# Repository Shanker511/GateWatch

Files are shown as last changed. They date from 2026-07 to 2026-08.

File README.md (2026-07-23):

# GateWatch

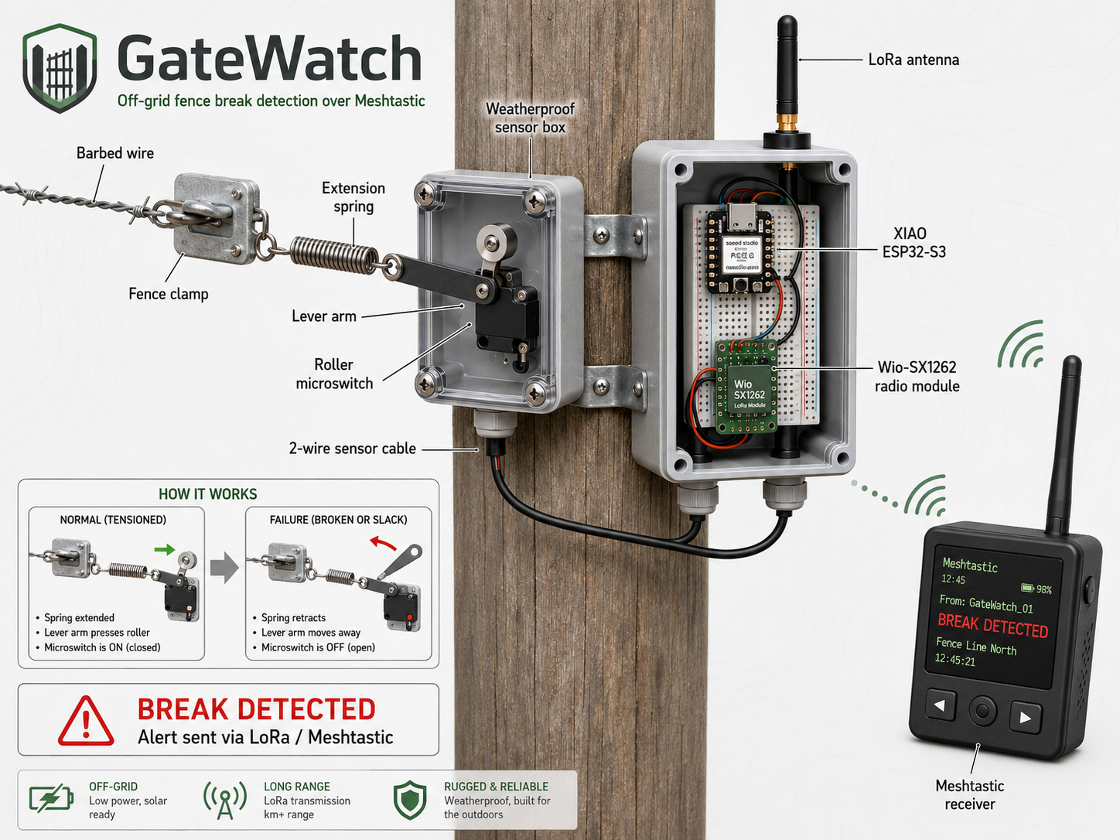
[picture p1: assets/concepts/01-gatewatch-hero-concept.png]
GateWatch concept


> **Current status:** hardware and firmware prototype in progress. The images in `assets/concepts/` are concept renderings, not photographs of a completed field unit. Real build photos, serial logs, range results, and a demonstration video will be added as testing progresses.

GateWatch is an off-grid fence integrity and activity monitor for farms, ranches, and remote property. A mechanical tension switch watches a barbed-wire fence section without electrically connecting the radio electronics to the fence. A PIR sensor provides a second indication of nearby movement. Alerts are transmitted through Meshtastic using a Seeed Studio XIAO ESP32-S3 and Wio-SX1262 radio module.

## Why this exists

A broken or slack fence may allow livestock to escape or create a security problem. Many fence lines are outside dependable cellular and Wi-Fi coverage. GateWatch is intended to provide a small, low-power field node that reports:

- `FENCE BREAK`
- `FENCE RESTORED`
- `MOTION DETECTED`
- `MOTION NEAR BROKEN FENCE`
- periodic status heartbeats
- a direct reply to `GW STATUS`

No cloud service or AI model is required for the core function.

## Project goals

| Goal | Status |
|---|---|
| Mechanical fence-tension sensor design | Designed; physical prototype pending |
| PIR motion input with cooldown | Implemented in prototype logic |
| XIAO ESP32-S3 + bare Wio-SX1262 wiring | Documented; bench validation pending |
| Standalone RadioLib smoke test | Source included; hardware build pending |
| Meshtastic firmware overlay | Source included; CI build validation pending |
| Desktop state-machine tests | Passing |
| Outdoor range and reliability test | Not started |
| Real prototype photos and demo video | Not started |

## Hardware

- Seeed Studio XIAO ESP32-S3
- Seeed Studio Wio-SX1262 bare radio module
- matched 868/915 MHz antenna for the configured region
- normally-closed roller-lever microswitch
- extension spring, lever, fence clamp, and weatherproof sensor box
- 3.3 V-compatible PIR motion sensor
- stable 3.3 V supply with local bulk and ceramic decoupling
- breadboard or perfboard for bench testing
- purpose-built carrier PCB for field use

The bare Wio-SX1262 is a surface-mount module. It cannot plug directly into a breadboard without a breakout, carrier PCB, or carefully strain-relieved wiring.

## System flow

```text
Barbed-wire tension mechanism ──> NC microswitch ──┐
                                                   ├─> XIAO ESP32-S3
PIR motion sensor ─────────────────────────────────┘         │
                                                             │ SPI
                                                             v
                                                       Wio-SX1262
                                                             │
                                                     Meshtastic mesh
                                                             │
                                                             v
                                                  Farmer's receiver/phone
```

## Correct prototype pin map

| Function | XIAO label | ESP32-S3 GPIO |
|---|---|---:|
| Wio DIO1 | D1 | 2 |
| Wio NRST | D2 | 3 |
| Wio BUSY | D3 | 4 |
| Wio NSS / CS | D4 | 5 |
| Wio RF switch / RXEN | D5 | 6 |
| Wio SCK | D8 | 7 |
| Wio MISO | D9 | 8 |
| Wio MOSI | D10 | 9 |
| Fence NC switch | D6 | 43 |
| PIR output | D7 | 44 |

See [`docs/WIRING.md`](docs/WIRING.md) before connecting hardware. The concept graphics are not authoritative wiring diagrams.

## Repository map

```text
assets/concepts/                 Ten concept renderings
firmware/radio_sensor_smoke_test Standalone RadioLib bench firmware
firmware/meshtastic-overlay      Custom Meshtastic variant and GateWatch module
docs/                            Build, wiring, safety, sensors, and test records
hardware/                        BOM and accurate wiring reference
simulator/                       Desktop state-machine model and tests
scripts/                         GitHub push and verification helpers
```

## Start testing

Read [`START_HERE.md`](START_HERE.md), then follow this order:

1. Review [`docs/SAFETY.md`](docs/SAFETY.md).
2. Build the breakout or carrier for the bare Wio-SX1262.
3. Wire the radio using [`docs/WIRING.md`](docs/WIRING.md).
4. Attach the correct antenna before transmitting.
5. Flash the standalone smoke test.
6. Verify fence and PIR state changes in the serial monitor.
7. Run the Meshtastic build workflow.
8. Record real test evidence in [`docs/FIELD_TEST_LOG_TEMPLATE.md`](docs/FIELD_TEST_LOG_TEMPLATE.md).

Desktop logic tests:

```bash
python -m unittest discover -s simulator -v
```

## Firmware tracks

### Standalone RadioLib smoke test

`firmware/radio_sensor_smoke_test/` tests the radio wiring and both sensors with ordinary point-to-point LoRa packets. It is deliberately separate from Meshtastic so hardware faults can be isolated first.

### Meshtastic overlay

`firmware/meshtastic-overlay/` adds:

- a custom `gatewatch-xiao-s3` hardware environment
- corrected exposed-header wiring for the bare Wio-SX1262
- fence and PIR input handling
- alert prioritization and message spacing
- heartbeat/status reporting
- `GW STATUS` and `GW HELP` commands

The overlay targets the current upstream Meshtastic source tree and is built by GitHub Actions. Until the workflow passes and real hardware is tested, treat this as development firmware rather than a finished release.

## License

GateWatch project code is released under GPL-3.0-or-later. Meshtastic and third-party libraries remain subject to their own upstream licenses.

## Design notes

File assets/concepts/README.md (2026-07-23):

# GateWatch Concept Renderings

These ten images describe the intended GateWatch product, deployment, and demonstration flow. They are concept artwork, not photographs and not authoritative wiring references.

1. Hero concept
2. System architecture concept
3. Mechanical tension sensor concept
4. Prototype wiring concept
5. Field deployment concept
6. Fence and motion event correlation
7. Enclosure exploded concept
8. Multi-zone coverage concept
9. Demonstration sequence concept
10. Farmer-use concept

Use `docs/WIRING.md` for actual pin assignments. Add real prototype photos under `assets/photos/`.

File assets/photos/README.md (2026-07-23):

# Real Prototype Photos

Add real, unedited build evidence here. Suggested filenames:

- `prototype-front.jpg`
- `prototype-wiring.jpg`
- `wio-carrier-closeup.jpg`
- `fence-sensor-installed.jpg`
- `field-test-wide.jpg`

Do not place concept renderings in this directory.

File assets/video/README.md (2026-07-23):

# Demo Video

Place a text file containing the final public video link here, or attach a compressed preview clip if repository size permits.

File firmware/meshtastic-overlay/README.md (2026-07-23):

# Meshtastic Overlay

This overlay adds a custom `gatewatch-xiao-s3` environment and a `GateWatchModule` to the official Meshtastic firmware source tree.

## Radio mapping

- D1 / GPIO2: Wio DIO1
- D2 / GPIO3: Wio NRST
- D3 / GPIO4: Wio BUSY
- D4 / GPIO5: Wio NSS/CS
- D5 / GPIO6: Wio RF_SW/RXEN
- D8 / GPIO7: Wio SCK
- D9 / GPIO8: Wio MISO
- D10 / GPIO9: Wio MOSI

## Sensor mapping

- D6 / GPIO43: normally-closed fence switch to ground
- D7 / GPIO44: active-high PIR output

## Build status

The source is intended to be compiled against current upstream Meshtastic firmware. The GitHub Actions workflow is the build authority. A successful desktop simulator test does not prove that this overlay compiles or that the radio wiring works.

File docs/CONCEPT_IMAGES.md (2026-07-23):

# Concept Image Notes

The ten images in `assets/concepts/` illustrate the intended product, field use, and presentation story. They were created before the physical prototype was assembled.

They are useful for:

- explaining the fence-tension mechanism
- showing the intended enclosure and deployment
- describing multi-zone mesh coverage
- planning the demonstration video
- communicating the motion/fence event logic

They are not authoritative for:

- exact pin assignments
- electrical voltage levels
- component dimensions
- final enclosure construction
- proof that the hardware has been built

Use `docs/WIRING.md` and `hardware/wiring-reference.svg` for wiring. Replace or supplement concept images with real photographs before competition judging.

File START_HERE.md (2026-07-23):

# GateWatch — Start Here

This repository targets a **Seeed Studio XIAO ESP32-S3**, a **bare Wio-SX1262 module**, a normally-closed mechanical fence-tension switch, and a 3.3 V-compatible PIR sensor.

## Do this first

1. Read `docs/SAFETY.md`.
2. Read `docs/WIRING.md` and verify every Wio module pad before soldering.
3. Build or obtain a carrier/breakout for the bare module. Do not hang jumper wires directly from unsupported pads.
4. Attach the correct antenna before powering firmware that may transmit.
5. Power the radio from 3.3 V only.

## Validation sequence

### 1. Run desktop tests

```powershell
python -m unittest discover -s simulator -v
```

### 2. Flash the standalone smoke test

```powershell
cd firmware\radio_sensor_smoke_test
python -m pip install platformio
python -m platformio run -e gatewatch-smoke-tx
python -m platformio run -e gatewatch-smoke-tx --target upload
python -m platformio device monitor --baud 115200
```

Expected serial events:

```text
BOOT fence=SECURE
FENCE BREAK
FENCE RESTORED
MOTION DETECTED
MOTION NEAR BROKEN FENCE
HEARTBEAT fence=SECURE motion=IDLE
```

### 3. Build the Meshtastic overlay

Windows PowerShell:

```powershell
cd firmware\meshtastic-overlay
.\scripts\build.ps1
```

Linux/macOS:

```bash
cd firmware/meshtastic-overlay
./scripts/build.sh
```

The GitHub Actions workflow performs the same build after the repository is pushed.

### 4. Collect evidence

Use `docs/FIELD_TEST_LOG_TEMPLATE.md` and add real photographs under `assets/photos/`. Concept art is not accepted as authenticity evidence.

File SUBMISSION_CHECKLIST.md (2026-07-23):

# Meshtastic Build-Off Submission Checklist

## Repository

- [x] Public project repository structure
- [x] Detailed README
- [x] Open-source license
- [x] Firmware source
- [x] Installation and build instructions
- [x] Hardware BOM
- [x] Wiring documentation
- [x] Safety notes
- [x] Test plan
- [ ] GitHub Actions Meshtastic build passes
- [ ] Release binary attached

## Authenticity and evidence

- [ ] Real front-view prototype photo
- [ ] Real wiring/carrier photo
- [ ] Real installed fence-sensor photo
- [ ] Meshtastic alert screenshot
- [ ] Serial initialization log
- [ ] Range-test log
- [ ] Power-test result
- [ ] Demo video of at least 30 seconds

## Technical validation

- [ ] SX1262 initializes without error
- [ ] Fence break alert repeats reliably
- [ ] Fence restoration alert repeats reliably
- [ ] PIR warm-up confirmed
- [ ] PIR cooldown confirmed
- [ ] Combined event alert confirmed
- [ ] Private Meshtastic channel configured
- [ ] Legal LoRa region configured
- [ ] Outdoor wiring strain relieved

## Presentation

- [ ] Problem and target user clearly explained
- [ ] Meshtastic is essential to the solution
- [ ] Known limitations listed
- [ ] Concept images labeled as concepts
- [ ] Real failures and fixes documented
- [ ] Final repository commit/tag created

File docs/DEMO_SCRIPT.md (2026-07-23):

# 60–90 Second Demo Script

1. Show the real XIAO ESP32-S3, Wio-SX1262, antenna, tension switch, and PIR sensor.
2. Show the receiver node and Meshtastic app.
3. State: “GateWatch monitors fence tension and nearby motion without cellular service.”
4. Show the fence wire under tension and confirm `SECURE`.
5. Release or cut the test wire.
6. Show the mechanical lever releasing the normally-closed microswitch.
7. Show the `FENCE BREAK` alert arriving on the receiver.
8. Trigger the PIR while the fence remains broken.
9. Show `MOTION NEAR BROKEN FENCE`.
10. Restore tension and show `FENCE RESTORED`.
11. End with a wide shot of both nodes and the actual test distance.

Do not use concept images as a substitute for the real demonstration.

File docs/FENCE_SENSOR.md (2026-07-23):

# Mechanical Fence Sensor

## Principle

Barbed wire is a poor supervised electrical conductor because it contacts ground, vegetation, staples, posts, moisture, corrosion, and other fence strands. GateWatch instead detects the mechanical result of a break: loss of tension.

## Mechanism

```text
barbed wire -> approved fence clamp -> extension spring -> lever -> NC roller microswitch
```

Normal tension holds the microswitch closed. A break, released clamp, or severe slack allows the spring and lever to move, opening the switch.

## Adjustment

- Mount the mechanism at a brace or termination post.
- Use an adjustment bolt or slotted bracket to set the trigger point.
- Keep the microswitch and electrical terminations inside a weather-resistant box.
- Do not make the small switch carry the fence's full structural load. A separate mechanical stop must absorb excessive tension.
- Divide long fences into named sections; one switch reports the affected section, not the exact break location.

Suggested node names include `GW-NORTH-01`, `GW-WEST-02`, and `GW-EAST-GATE`.

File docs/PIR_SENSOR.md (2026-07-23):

# PIR Motion Sensor

The PIR input is supplemental evidence. It does not identify a person or distinguish a human from livestock, wildlife, moving vegetation, or rapid temperature changes.

## Firmware controls

- 30-second start-up warm-up
- 200 ms input debounce
- 60-second event cooldown
- Separate motion state from fence state
- Combined high-priority alert when motion occurs while the fence state is broken

## Placement

Mount the PIR below or beside the radio enclosure and point it along the approach corridor rather than directly at the sky, sun, reflective water, or rapidly heating metal. A hood reduces rain and direct solar exposure.

For first tests, use a small 3.3 V PIR module. Confirm its output voltage with a meter before connecting it to the XIAO.

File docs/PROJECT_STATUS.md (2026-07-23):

# Project Status

## Completed in repository

- problem definition and architecture
- mechanical fence-tension sensor design
- PIR event behavior
- standalone RadioLib smoke-test source
- Meshtastic overlay source
- desktop sensor-state simulator
- automated desktop tests
- BOM, wiring, safety, test plan, and concept materials

## Not yet validated

- soldered Wio-SX1262 carrier
- radio initialization on the user's exact module revision
- Meshtastic overlay compilation in GitHub Actions
- end-to-end Meshtastic message reception
- mechanical trigger repeatability
- outdoor weather resistance
- battery life and solar charging
- range testing

## Evidence policy

Generated concept images are retained as design and presentation material. They must not be represented as photographs of the physical build. Add real evidence to:

```text
assets/photos/
assets/screenshots/
assets/video/
docs/test-results/
```

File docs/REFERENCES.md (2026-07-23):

# References

- Meshtastic firmware repository: https://github.com/meshtastic/firmware
- Meshtastic Detection Sensor module documentation: https://meshtastic.org/docs/configuration/module/detection-sensor/
- Meshtastic issue documenting the exposed-header Wio-SX1262 pin definition: https://github.com/meshtastic/firmware/issues/8409
- Seeed Studio Meshtastic Build-Off 2026: https://www.seeedstudio.com/meshtastic-build-off
- Official competition repository: https://github.com/Seeed-Projects/meshtastic-build-off-2026
- Seeed Studio XIAO ESP32-S3 pin multiplexing: https://wiki.seeedstudio.com/xiao_esp32s3_pin_multiplexing/
- Wio-SX1262 product page: https://www.seeedstudio.com/Wio-SX1262-Wireless-Module-p-5981.html

Pin assignments and software interfaces can change. Freeze a known Meshtastic commit after the first successful build and hardware test.

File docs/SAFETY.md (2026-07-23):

# Safety

- Do not connect the XIAO, Wio-SX1262, microswitch, PIR, or breadboard directly to an energized electric-fence conductor.
- GateWatch v0.2 uses a mechanically actuated, electrically isolated switch.
- Barbed wire can cut skin and can release stored energy when tension changes. Wear eye protection, gloves, long sleeves, and use proper fence tools.
- Install a mechanical stop so the microswitch and enclosure do not carry fence tension.
- Never transmit without the correct antenna attached.
- Do not place a breadboard prototype outdoors unattended.
- Use a protected battery, fused wiring, strain relief, weather-rated cable glands, and a sealed enclosure for field trials.
- Follow local radio-region settings and applicable fencing, electrical, workplace, and land-use requirements.

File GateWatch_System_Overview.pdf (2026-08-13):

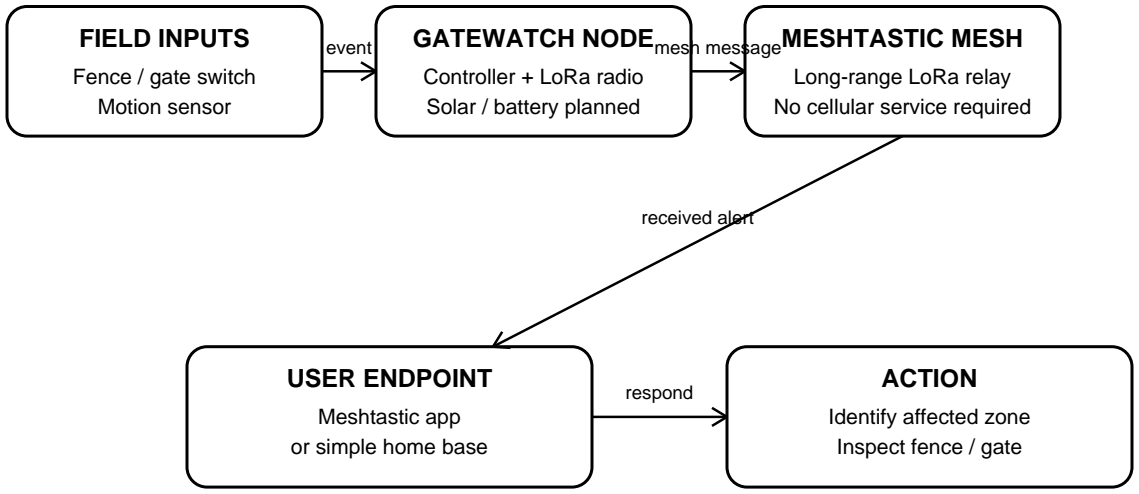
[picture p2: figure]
FIELD INPUTS; Fence / gate switch Motion sensor; GATEWATCH NODE; Controller + LoRa radio Solar / battery planned; MESHTASTIC MESH; Long-range LoRa relay No cellular service required; event; mesh message; USER ENDPOINT; Meshtastic app or simple home base; ACTION; Identify affected zone Inspect fence / gate; received alert; respond

GateWatch - Meshtastic Build-Off 2026 | Page 1

# GateWatch

How the Meshtastic Fence Monitoring System Works

Project: GateWatch / Farmer's Fence Mesh | Build-Off: Meshtastic Build-Off 2026
Purpose: Remote fence, gate, and movement alerts | Status: Concept / design; physical validation pending

## 1. What GateWatch Is

GateWatch is a proposed low-power monitoring system for farms and ranches where long fence lines may be outside cellular or Wi-Fi coverage. A small field node watches for conditions such as a fence breach, an open gate, or nearby movement. When an event is detected, the node sends a message through a Meshtastic LoRa mesh to the farmer's phone or a simple home-base device.

The design is intended to reduce the time spent manually checking remote fence sections and to provide an early warning when livestock containment or property security may be affected.

## 2. System Architecture

The key idea is simple: sensors generate an event, a field node converts that event into a message, Meshtastic carries the message across the property, and the user receives enough information to decide where to inspect.

## 3. How an Alert Moves Through the System

### 1. Monitor

A GateWatch field node continuously watches connected inputs. Planned examples include a fence or gate switch and a motion sensor.

### 2. Detect

If an input changes state - for example, a gate opens or a fence-monitoring switch indicates a possible breach - the controller records the event.

### 3. Package

The controller creates a short alert message identifying the node or monitored zone and the type of event.

### 4. Transmit

The LoRa radio sends the alert into the Meshtastic network. Nearby Meshtastic nodes can relay the packet, allowing coverage beyond a single direct radio link.

### 5. Receive

The alert reaches a Meshtastic-connected phone or a simple wireless home-base device.

### 6. Respond

The user can identify the affected section and inspect the fence, gate, post, or surrounding area.

## 4. Main System Blocks

Block | Role in GateWatch
Field sensors | Detect physical changes such as gate state, fence condition, or motion.
Controller | Reads sensors, applies event logic, and creates an alert.
LoRa radio | Provides long-range, low-bandwidth wireless communication.
Meshtastic mesh | Relays messages between nodes without requiring normal cellular infrastructure.
Power system | Planned solar and battery power for remote, low-maintenance operation.
User endpoint | Meshtastic app or simple base station used to receive alerts and identify the affected area.

## 5. Example Deployment

A ranch could place GateWatch nodes at high-risk locations such as gates, isolated fence corners, road crossings, or sections frequently damaged by wildlife or fallen branches. The nodes would communicate through the Meshtastic mesh, so a node that cannot directly reach the house could potentially pass its alert through another mesh node.

### Example event:

Fence section B changes state -> GateWatch Node B detects the event -> the node transmits an alert -> the message is relayed through the Meshtastic mesh -> the farmer receives the alert and checks section B.

## 6. Why Meshtastic Fits the Concept

GateWatch is aimed at locations where conventional infrastructure may be unavailable or undesirable. Meshtastic uses LoRa radios and mesh networking, making it suitable for small event messages over comparatively long distances while allowing intermediate nodes to relay traffic.

The project is not intended to stream video or large amounts of data. Its job is to move small, useful status and alarm messages from remote points back to the user.

## 7. Current Project Status

As of the Meshtastic Build-Off 2026 final review period, GateWatch should be treated as a concept and system design rather than a completed, field-validated product. The physical prototype, measured radio range, solar/battery endurance, environmental enclosure performance, and real-world sensor behavior still require testing.

This document describes the intended operation of the system. It does not claim that the full system has already been assembled or validated in the field.

## 8. Next Build Milestones

- Assemble one field node and verify its sensor inputs.
- Establish Meshtastic radio communication between the field node and a receiving node.
- Generate real fence/gate and movement events and confirm alert delivery.
- Measure practical range on representative rural terrain.
- Measure current draw and validate the solar/battery power budget.
- Install the electronics in a weather-resistant enclosure and perform an outdoor field trial.

### Repository

https://github.com/Shanker511/GateWatch

Prepared as a concise technical overview for the GateWatch Meshtastic Build-Off project.

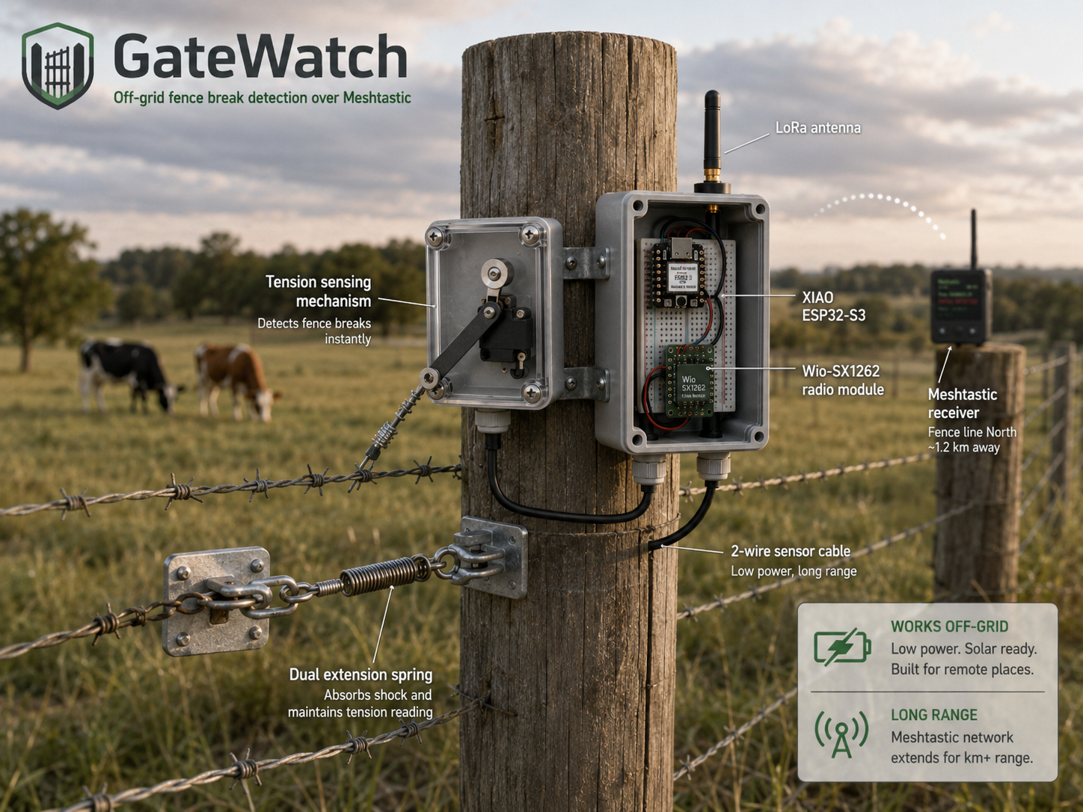
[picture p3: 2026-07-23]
assets/concepts/05-field-deployment-concept.png

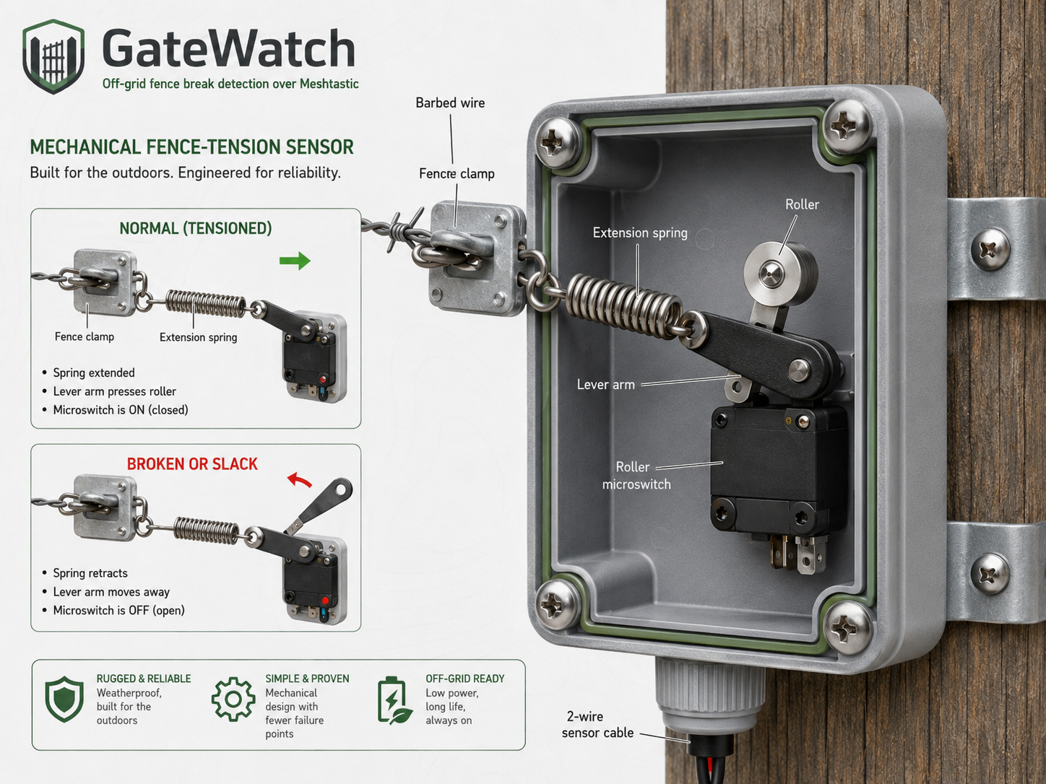
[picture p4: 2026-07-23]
assets/concepts/03-mechanical-tension-sensor-concept.png

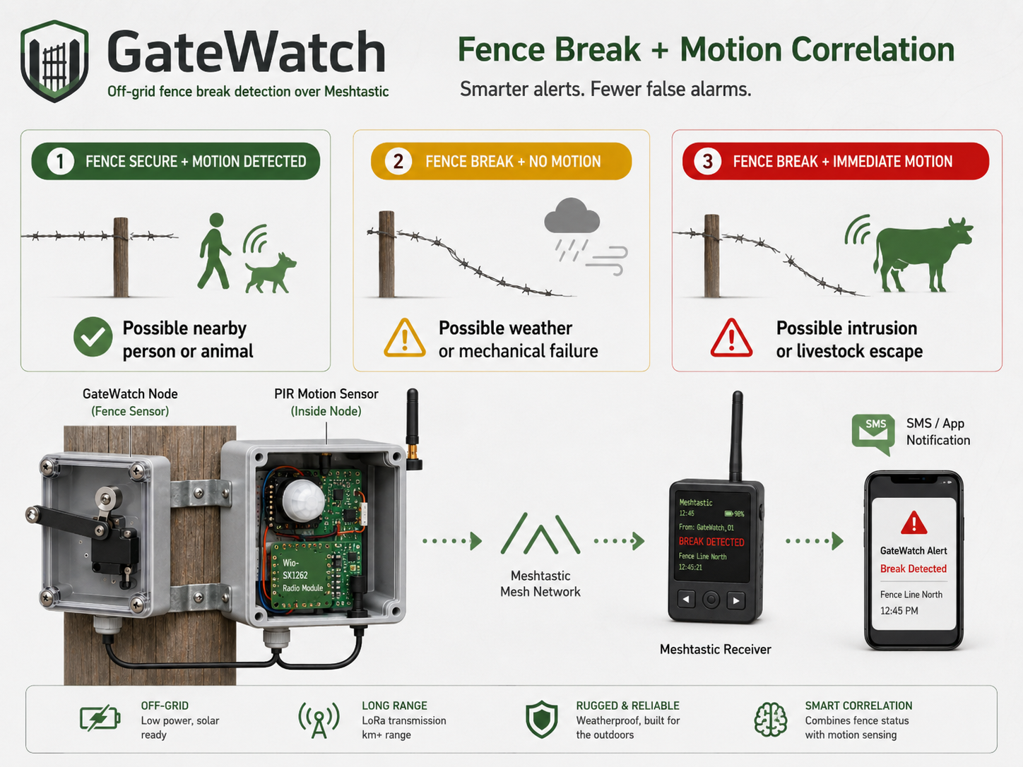
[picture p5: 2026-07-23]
assets/concepts/06-motion-correlation-concept.png

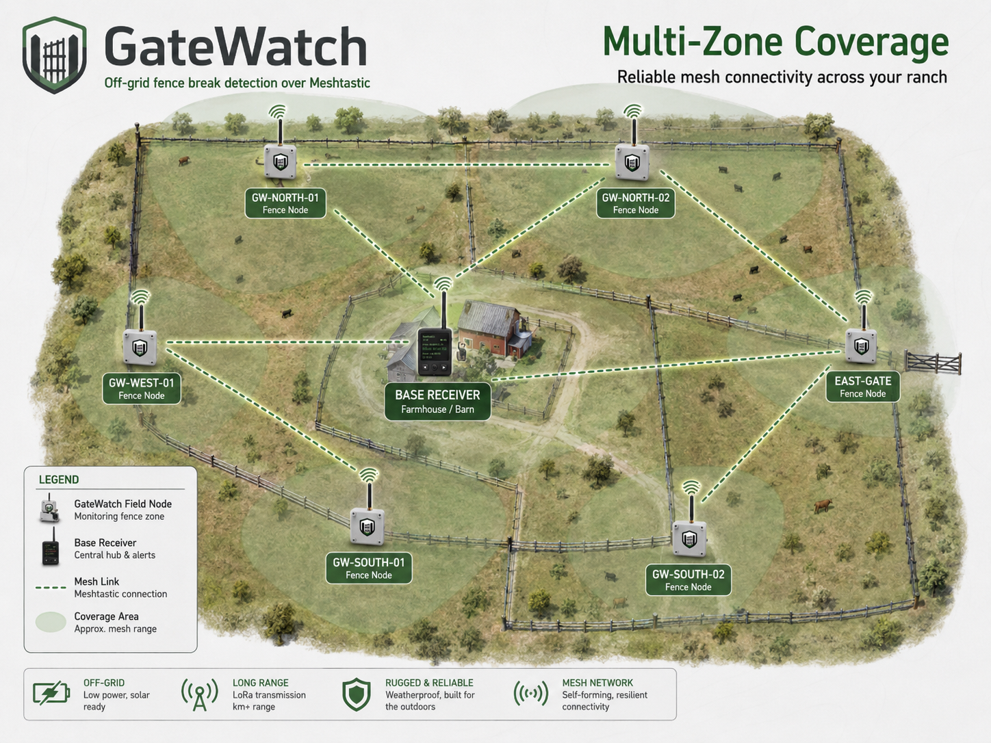
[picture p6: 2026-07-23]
assets/concepts/08-multi-zone-coverage-concept.png

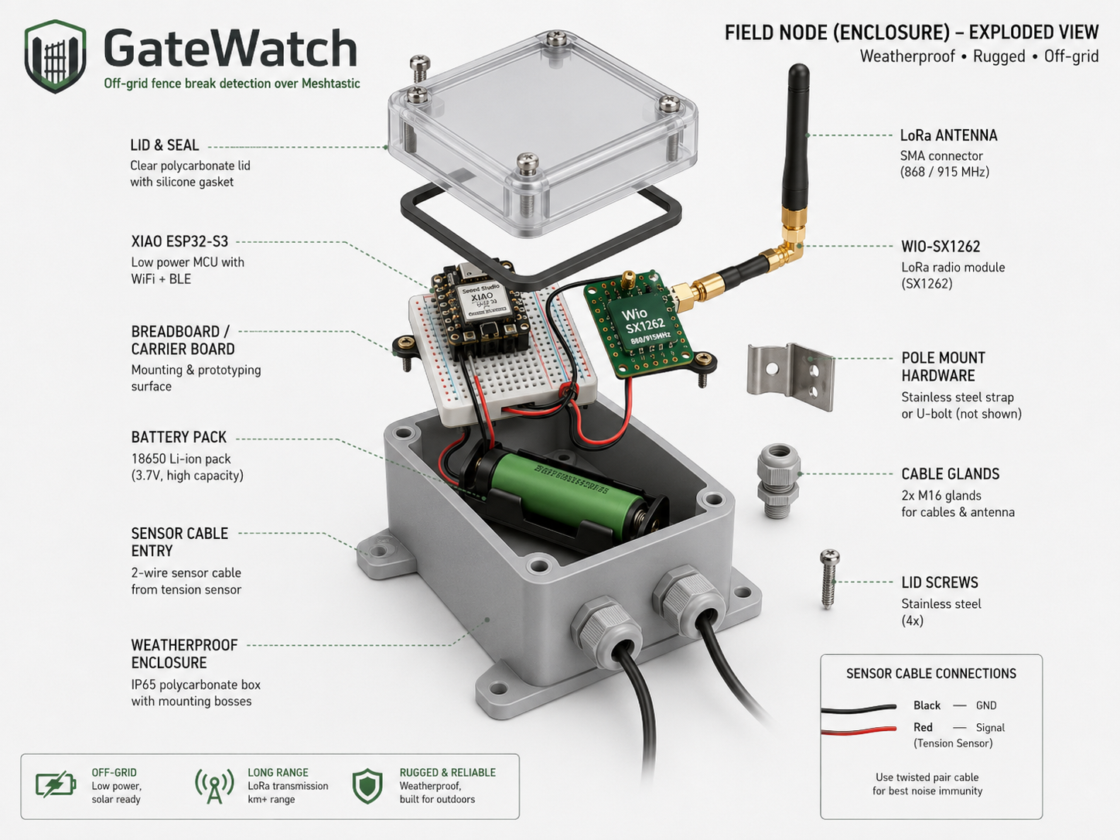
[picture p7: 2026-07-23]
assets/concepts/07-enclosure-exploded-concept.png

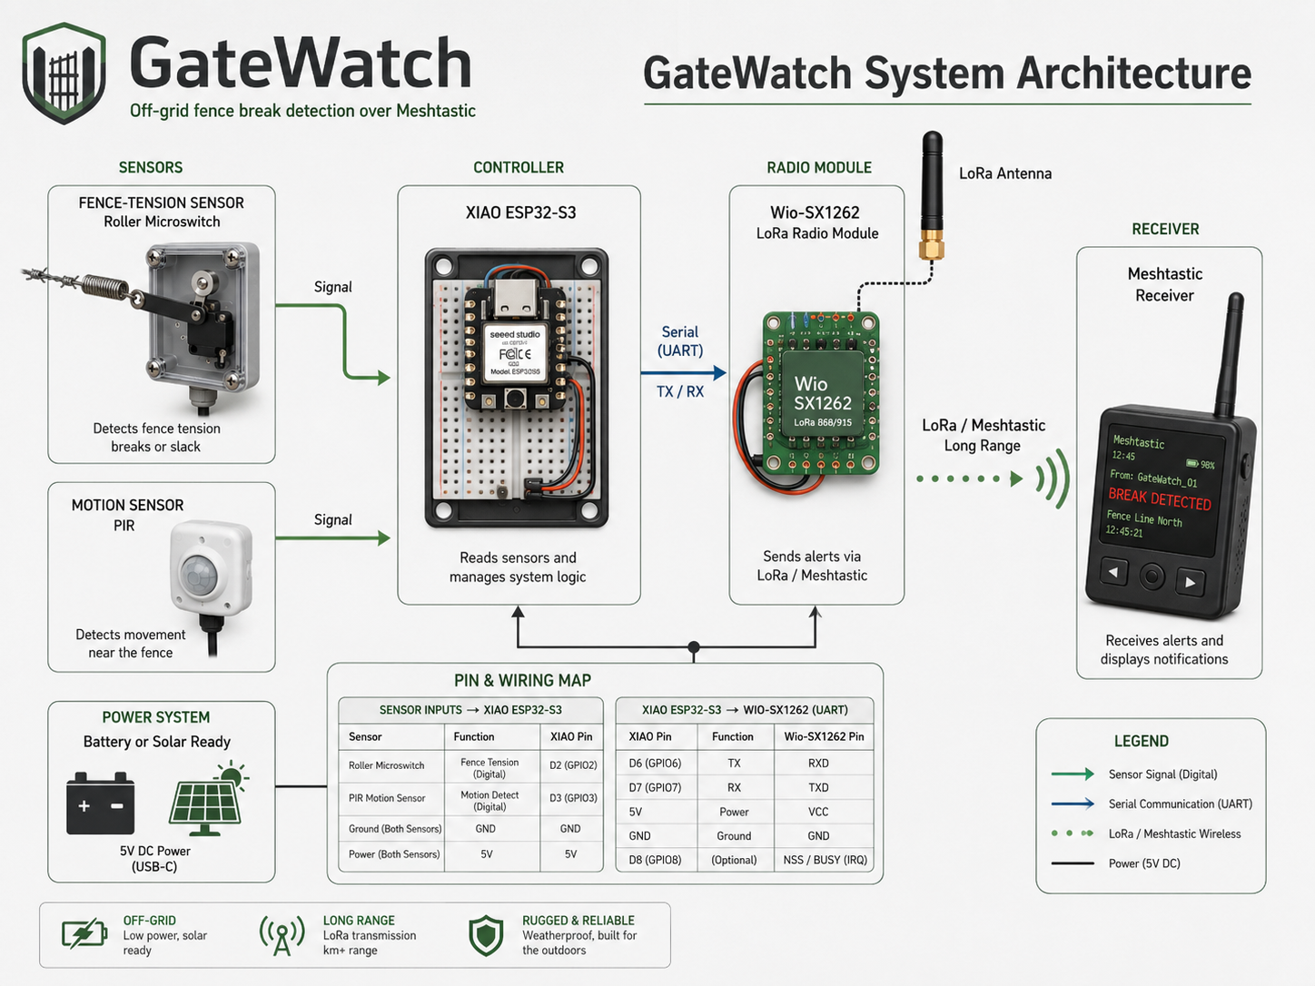
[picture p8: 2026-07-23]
assets/concepts/02-system-architecture-concept.png

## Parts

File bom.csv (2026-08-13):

Item | Quantity | Node | Stage | Notes
Seeed Studio XIAO ESP32-S3 | 3 | Base + 2 Sentinels | Required | Host MCU
Seeed Studio Wio-SX1262 bare module | 3 | Base + 2 Sentinels | Required | SX1262 Meshtastic radio
Matched 868/915 MHz antenna | 3 | Base + 2 Sentinels | Required | Match configured legal region and attach before transmit
Wio-SX1262 breakout/carrier PCB | 3 | Base + 2 Sentinels | Required | Bare module cannot plug directly into a breadboard
Normally-closed roller-lever microswitch | 2 | Sentinels | Required | Fence-tension input
3.3 V-compatible PIR motion sensor | 2 | Sentinels | Required | Active-high output preferred
DHT11 temperature/humidity module | 2 | Sentinels | Required | Use a vented shaded chamber
4.7-5.1 kOhm resistor | 2 | Sentinels | Conditional | Required for bare four-pin DHT11; many modules include it
Extension spring | 2 | Sentinels | Required | Mechanical tension mechanism
Fence wire clamp | 2 | Sentinels | Required | Use fencing-rated hardware
Lever arm and pivot hardware | 2 | Sentinels | Required | Adjustable trigger geometry
Weather-resistant sensor enclosure | 2 | Sentinels | Field test | Protect switch mechanism
Weather-resistant electronics enclosure | 2 | Sentinels | Field test | Protect radio electronics
Vented DHT11 radiation shield or chamber | 2 | Sentinels | Field test | Protect from rain and direct sun while allowing airflow
Cable glands | 6-8 | Sentinels | Field test | Strain relief and weather sealing
100 uF electrolytic capacitor | 3 | Base + 2 Sentinels | Required | Place near each radio supply
100 nF ceramic capacitor | 6 | Base + 2 Sentinels | Required | Radio decoupling plus DHT11 supply filtering
1 kOhm resistor | 2 | Sentinels | Recommended | Fence input protection
Two-conductor UV-resistant cable | As needed | Sentinels | Field test | Sensor to electronics enclosure
Breadboard and jumper wires | 3 | Bench only | Bench only | Not suitable for outdoor deployment
USB power supply | 1 | Base | Required | Continuous dashboard bridge power
Protected battery pack or USB power | 2 | Sentinels | Bench/field | Confirm voltage regulation and current capability

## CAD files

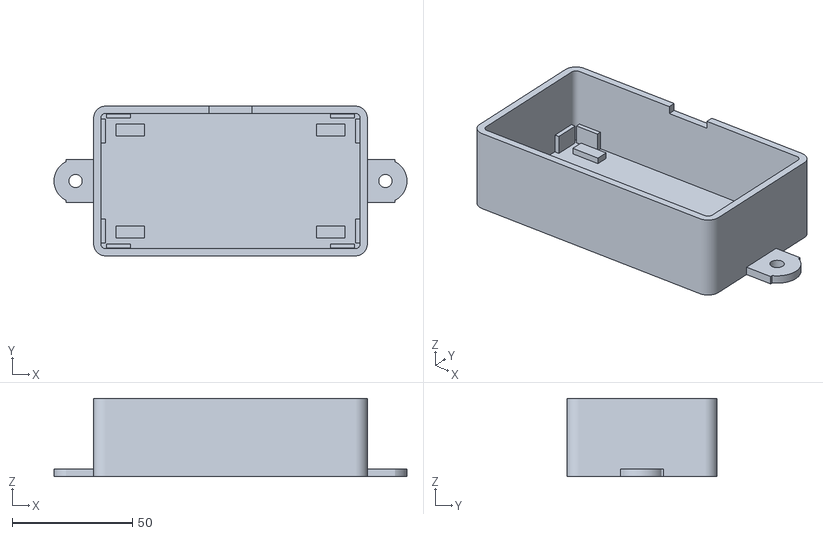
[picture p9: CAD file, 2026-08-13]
GateWatch_Base.stl
147.0 x 62.4 x 32.6

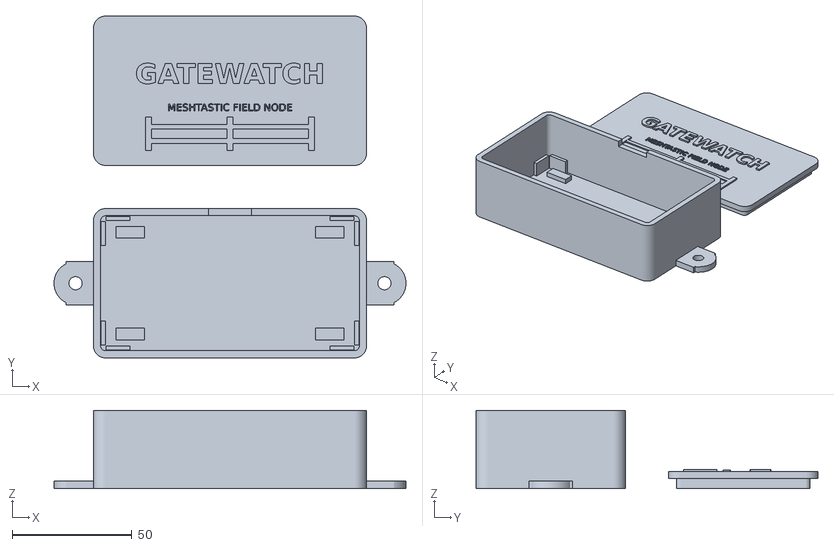
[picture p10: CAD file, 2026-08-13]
GateWatch_PrintPlate.stl
147.0 x 142.8 x 32.6

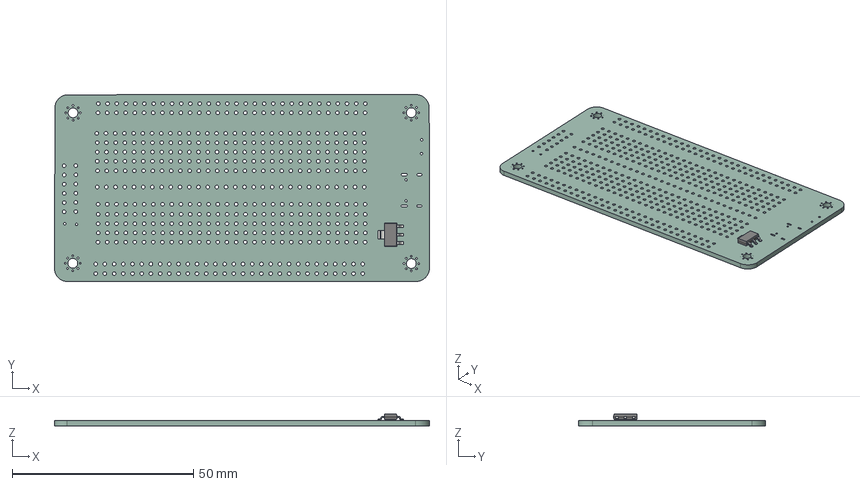
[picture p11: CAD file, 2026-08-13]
.step
103.4 x 51.6 x 3.34 mm
SOT-223
Protoboard_PCB

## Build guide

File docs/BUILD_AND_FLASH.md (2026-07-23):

# Build and Flash

## Standalone smoke test

The smoke test verifies the XIAO, Wio-SX1262 wiring, tension switch, PIR sensor, and point-to-point LoRa transmission before the full Meshtastic build is introduced.

Requirements:

- Python 3
- PlatformIO Core or VS Code with PlatformIO
- USB data cable
- antenna attached to the Wio-SX1262

```bash
cd firmware/radio_sensor_smoke_test
python -m pip install platformio
python -m platformio run -e gatewatch-smoke-tx
python -m platformio run -e gatewatch-smoke-tx --target upload
python -m platformio device monitor --baud 115200
```

Optional matching point-to-point receiver:

```bash
python -m platformio run -e gatewatch-smoke-rx
python -m platformio run -e gatewatch-smoke-rx --target upload
```

The smoke-test packets are ordinary LoRa packets and are not Meshtastic-compatible.

## Meshtastic overlay

Windows:

```powershell
cd firmware\meshtastic-overlay
.\scripts\build.ps1
```

Linux/macOS:

```bash
cd firmware/meshtastic-overlay
./scripts/build.sh
```

The scripts clone the official firmware, apply the GateWatch variant and module, patch module initialization, and run PlatformIO.

Set `MESHTASTIC_REF` to a known release or commit when freezing a tested competition build.

After flashing:

1. Set the legal LoRa region.
2. Configure a private primary channel shared by the field node and receiver.
3. Confirm normal text messages between the nodes.
4. Trigger the fence switch and PIR.
5. Send `GW STATUS` from the receiver.

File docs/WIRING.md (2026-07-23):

# Wiring Reference

This document is the authoritative prototype wiring reference. The images under `assets/concepts/` are communication artwork and may simplify or mislabel details.

## Bare Wio-SX1262 to XIAO ESP32-S3

The following exposed-header mapping is based on the working header-board pin definition documented in the Meshtastic firmware project.

| Wio signal | XIAO label | ESP32-S3 GPIO | Notes |
|---|---|---:|---|
| DIO1 | D1 | 2 | SX1262 interrupt |
| NRST | D2 | 3 | Radio reset |
| BUSY | D3 | 4 | Radio busy line |
| NSS / CS | D4 | 5 | SPI chip select |
| RF_SW / RXEN | D5 | 6 | External receive switch control |
| SCK | D8 | 7 | SPI clock |
| MISO | D9 | 8 | SPI radio to MCU |
| MOSI | D10 | 9 | SPI MCU to radio |
| VCC | 3V3 | — | 3.3 V only |
| GND | GND | — | Connect all grounds |
| ANT | U.FL/IPEX | — | Matched antenna; no GPIO connection |

Use short wiring and a solid ground reference. Add a 100 µF electrolytic capacitor and a 100 nF ceramic capacitor close to the radio module.

## Fence tension switch

Use the normally-closed contact. This creates a fail-safe behavior where a broken sensor cable also appears as an alarm.

```text
XIAO D6 / GPIO43 ---- microswitch NC
GND ----------------- microswitch COM
```

Firmware mode: `INPUT_PULLUP`

| Electrical state | Reading | GateWatch state |
|---|---|---|
| NC switch closed | LOW | SECURE |
| Switch open | HIGH | FENCE BREAK |
| Cable cut/disconnected | HIGH | FENCE BREAK |

For long cable runs, place a 1 kΩ series resistor near the XIAO input and a 100 nF capacitor from the GPIO side of the resistor to ground.

## PIR motion sensor

Only use a PIR output that is safe for 3.3 V logic.

```text
PIR VCC ---- XIAO 3V3
PIR GND ---- XIAO GND
PIR OUT ---- XIAO D7 / GPIO44
```

| PIR output | GateWatch state |
|---|---|
| LOW | IDLE |
| HIGH | MOTION |

The firmware ignores PIR activity during warm-up and applies a cooldown to prevent mesh flooding.

## Breadboard warning

The Wio-SX1262 is a surface-mount module. It must be mounted to a breakout, carrier, or mechanically secured perfboard assembly. Do not use unsupported flying wires attached directly to the module pads for field testing.

## Power

- Wio-SX1262 supply: 3.3 V only
- Bench power: XIAO USB-C is acceptable
- Place decoupling close to the radio
- Attach the antenna before transmitting
- Set the legal Meshtastic region before over-the-air tests

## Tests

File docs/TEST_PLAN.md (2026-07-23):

# Test Plan

Record every test with date, firmware commit, node name, power source, antenna, distance, weather, result, and photo/video reference.

## Bench tests

1. Boot with fence switch closed. Verify `SECURE` and no false break event.
2. Open switch for less than debounce time. Verify no alert.
3. Hold switch open. Verify one `FENCE BREAK` alert.
4. Close switch. Verify one `FENCE RESTORED` alert.
5. Trigger PIR after warm-up. Verify one `MOTION DETECTED` alert.
6. Retrigger PIR during cooldown. Verify no message flood.
7. Open fence switch, then trigger PIR. Verify `MOTION NEAR BROKEN FENCE`.
8. Send `GW STATUS`. Verify direct status reply.
9. Leave operating for at least one heartbeat interval. Verify status heartbeat.
10. Power-cycle with fence open. Verify startup state is reported correctly after initialization.

## Field tests

- Test at 25 m, 100 m, 250 m, and a realistic property distance.
- Test normal line of sight and with terrain/building obstruction.
- Operate for at least four hours on the intended battery.
- Pull, release, and repair the mechanical test fence several times.
- Note false triggers from wind, livestock contact, thermal changes, and enclosure movement.

## Pass criteria

- Every sustained break produces exactly one break alert within the configured timing window.
- Every restoration produces exactly one restoration alert.
- PIR events remain rate-limited.
- Status command receives a reply.
- No resets or radio initialization failures occur during the field session.

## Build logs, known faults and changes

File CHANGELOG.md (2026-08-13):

# Changelog

## 0.5.2 — 2026-07-22

- Standardized the build as one Base node and two identical Sentinel nodes.
- Added DHT11 temperature and humidity sensing on XIAO D0 / GPIO1.
- Added DHT11 sampling to the standalone smoke test and Meshtastic overlay.
- Added `GW ENV` command and environmental fields in status and heartbeat messages.
- Added dashboard temperature/humidity parsing, storage, display, demo data, and tests.
- Updated the three-node BOM and authoritative wiring documentation.

## 0.5.1 — 2026-07-22

- Added a double-click Windows GitHub publishing helper.
- Updated the automated commit message for the dashboard gallery and dark-theme additions.
- Re-ran repository verification before packaging.

## 0.5.0 — 2026-07-22

- Added dashboard and mobile concept screenshots in both light and dark themes.
- Added screenshot gallery to the main README.
- Added documentation clarifying the dashboard visual direction and current dark operational theme.
- Updated dashboard docs so the repository presents a clearer product story for the Meshtastic Build-Off.

## 0.4.0 — 2026-07-22

- Added the local GateWatch map dashboard.
- Added GeoJSON import and export, node placement, and zone drawing.
- Added the Meshtastic USB bridge and live dashboard updates.
- Added dashboard server tests and example demo state.

## 0.2.0 — 2026-07-22

- Reworked field node for XIAO ESP32-S3 and bare Wio-SX1262 module.
- Added fence tension-loss input.
- Added PIR motion input with warm-up, debounce, and cooldown protection.
- Added combined `MOTION NEAR BROKEN FENCE` alert.
- Added `GW STATUS` and `GW HELP` Meshtastic commands.
- Added scheduled heartbeat and outbound message spacing.
- Added standalone LoRa hardware smoke test.
- Added desktop simulator and automated tests.

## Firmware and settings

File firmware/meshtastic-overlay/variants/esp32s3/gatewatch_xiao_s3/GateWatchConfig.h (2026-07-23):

#pragma once

// Human-readable identity included in every GateWatch application message.
#define GATEWATCH_NODE_NAME "GW-NORTH-01"

// Sensors on exposed XIAO header pins.
#define GATEWATCH_FENCE_PIN 43 // XIAO D6; NC switch to GND
#define GATEWATCH_PIR_PIN 44   // XIAO D7; active HIGH

#define GATEWATCH_FENCE_BREAK_LEVEL HIGH
#define GATEWATCH_PIR_ACTIVE_LEVEL HIGH

#define GATEWATCH_FENCE_DEBOUNCE_MS 750UL
#define GATEWATCH_PIR_DEBOUNCE_MS 200UL
#define GATEWATCH_PIR_WARMUP_MS 30000UL
#define GATEWATCH_PIR_COOLDOWN_MS 60000UL
#define GATEWATCH_HEARTBEAT_MS 900000UL
#define GATEWATCH_TX_SPACING_MS 15000UL
#define GATEWATCH_STARTUP_REPORT_MS 35000UL

// Meshtastic channel index used for broadcast alerts. Channel 0 is the primary channel.
#define GATEWATCH_ALERT_CHANNEL 0

// Bell character can trigger audible/vibration notifications in some clients.
#define GATEWATCH_APPEND_BELL 1

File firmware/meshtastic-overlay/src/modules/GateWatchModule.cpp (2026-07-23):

#include "GateWatchModule.h"

#include "GateWatchConfig.h"
#include "MeshService.h"
#include "mesh/Channels.h"
#include "configuration.h"
#include "main.h"

#include <Arduino.h>
#include <ctype.h>
#include <stdio.h>
#include <string.h>

GateWatchModule::GateWatchModule()
    : SinglePortModule("gatewatch", meshtastic_PortNum_TEXT_MESSAGE_APP), concurrency::OSThread("GateWatch")
{
}

bool GateWatchModule::updateInput(DebouncedInput &input, bool raw, uint32_t debounceMs, uint32_t now)
{
    if (!input.initialized) {
        input.raw = raw;
        input.stable = raw;
        input.changedAt = now;
        input.initialized = true;
        return false;
    }

    if (raw != input.raw) {
        input.raw = raw;
        input.changedAt = now;
    }

    if (input.stable != input.raw && (uint32_t)(now - input.changedAt) >= debounceMs) {
        input.stable = input.raw;
        return true;
    }
    return false;
}

int32_t GateWatchModule::runOnce()
{
    const uint32_t now = millis();

    if (firstRun) {
        firstRun = false;
        bootAt = now;
        lastHeartbeatAt = now;
        pinMode(GATEWATCH_FENCE_PIN, INPUT_PULLUP);
        pinMode(GATEWATCH_PIR_PIN, INPUT_PULLDOWN);

        const bool rawFenceBroken = digitalRead(GATEWATCH_FENCE_PIN) == GATEWATCH_FENCE_BREAK_LEVEL;
        const bool rawPirActive = digitalRead(GATEWATCH_PIR_PIN) == GATEWATCH_PIR_ACTIVE_LEVEL;
        updateInput(fenceInput, rawFenceBroken, 0, now);
        updateInput(pirInput, rawPirActive, 0, now);
        fenceBroken = fenceInput.stable;
        pirActive = false; // Ignore PIR state until warm-up completes.

        LOG_INFO("GateWatch initialized: fence=%s", fenceBroken ? "BROKEN" : "SECURE");
        return setStartDelay();
    }

    const bool rawFenceBroken = digitalRead(GATEWATCH_FENCE_PIN) == GATEWATCH_FENCE_BREAK_LEVEL;
    if (updateInput(fenceInput, rawFenceBroken, GATEWATCH_FENCE_DEBOUNCE_MS, now)) {
        onFenceChanged(fenceInput.stable, now);
    }

    const bool pirWarmed = (uint32_t)(now - bootAt) >= GATEWATCH_PIR_WARMUP_MS;
    if (pirWarmed) {
        const bool rawPirActive = digitalRead(GATEWATCH_PIR_PIN) == GATEWATCH_PIR_ACTIVE_LEVEL;
        if (updateInput(pirInput, rawPirActive, GATEWATCH_PIR_DEBOUNCE_MS, now)) {
            onPirChanged(pirInput.stable, now);
        }
    }

    if (!startupQueued && (uint32_t)(now - bootAt) >= GATEWATCH_STARTUP_REPORT_MS) {
        startupQueued = true;
        queueStatus(BROADCAST_NODE, GATEWATCH_ALERT_CHANNEL, false);
    }

    if ((uint32_t)(now - lastHeartbeatAt) >= GATEWATCH_HEARTBEAT_MS) {
        lastHeartbeatAt = now;
        queueStatus(BROADCAST_NODE, GATEWATCH_ALERT_CHANNEL, true);
    }

    transmitNext(now);
    return 100;
}

void GateWatchModule::onFenceChanged(bool broken, uint32_t now)
{
    (void)now;
    fenceBroken = broken;
    char message[meshtastic_Constants_DATA_PAYLOAD_LEN + 1];
    snprintf(message, sizeof(message), "%s | %s", GATEWATCH_NODE_NAME, broken ? "FENCE BREAK" : "FENCE RESTORED");
    enqueue(message, broken ? AlertPriority::BREAK : AlertPriority::RESTORE);
    LOG_WARN("GateWatch fence state: %s", broken ? "BROKEN" : "SECURE");
}

void GateWatchModule::onPirChanged(bool active, uint32_t now)
{
    pirActive = active;
    if (!active)
        return;

    if (lastMotionAlertAt != 0 && (uint32_t)(now - lastMotionAlertAt) < GATEWATCH_PIR_COOLDOWN_MS)
        return;

    lastMotionAlertAt = now;
    char message[meshtastic_Constants_DATA_PAYLOAD_LEN + 1];
    snprintf(message, sizeof(message), "%s | %s", GATEWATCH_NODE_NAME,
             fenceBroken ? "MOTION NEAR BROKEN FENCE" : "MOTION DETECTED");
    enqueue(message, fenceBroken ? AlertPriority::BREAK : AlertPriority::MOTION);
    LOG_INFO("GateWatch PIR event; fence=%s", fenceBroken ? "BROKEN" : "SECURE");
}

void GateWatchModule::queueStatus(uint32_t to, uint8_t channel, bool heartbeat)
{
    char message[meshtastic_Constants_DATA_PAYLOAD_LEN + 1];
    const unsigned long uptimeMinutes = millis() / 60000UL;
    snprintf(message, sizeof(message), "%s | %s fence=%s motion=%s up=%lum", GATEWATCH_NODE_NAME,
             heartbeat ? "HEARTBEAT" : "STATUS", fenceBroken ? "BROKEN" : "SECURE",
             pirActive ? "ACTIVE" : "IDLE", uptimeMinutes);
    enqueue(message, AlertPriority::HEARTBEAT, to, channel);
}

bool GateWatchModule::enqueue(const char *text, AlertPriority priority, uint32_t to, uint8_t channel)
{
    int empty = -1;
    int replace = -1;
    AlertPriority lowest = AlertPriority::BREAK;

    for (uint8_t i = 0; i < QUEUE_SIZE; ++i) {
        if (!queue[i].used) {
            empty = i;
            break;
        }
        if (queue[i].priority <= lowest) {
            lowest = queue[i].priority;
            replace = i;
        }
    }

    int slot = empty;
    if (slot < 0 && replace >= 0 && priority > lowest)
        slot = replace;
    if (slot < 0) {
        LOG_WARN("GateWatch queue full; dropping message: %s", text);
        return false;
    }

    queue[slot].used = true;
    queue[slot].to = to;
    queue[slot].channel = channel;
    queue[slot].priority = priority;
    strncpy(queue[slot].text, text, sizeof(queue[slot].text) - 1);
    queue[slot].text[sizeof(queue[slot].text) - 1] = '\0';
    return true;
}

void GateWatchModule::transmitNext(uint32_t now)
{
    if ((uint32_t)(now - lastTxAt) < GATEWATCH_TX_SPACING_MS)
        return;

    int selected = -1;
    AlertPriority best = AlertPriority::HEARTBEAT;
    for (uint8_t i = 0; i < QUEUE_SIZE; ++i) {
        if (!queue[i].used)
            continue;
        if (selected < 0 || queue[i].priority > best) {
            selected = i;
            best = queue[i].priority;
        }
    }

    if (selected < 0)
        return;

    if (sendText(queue[selected].text, queue[selected].to, queue[selected].channel)) {
        queue[selected].used = false;
        lastTxAt = now;
    }
}

bool GateWatchModule::sendText(const char *text, uint32_t to, uint8_t channel)
{
    if (to == BROADCAST_NODE && channels.isDefaultChannel(channel)) {
        LOG_ERROR("GateWatch will not send application alerts on the default public channel");
        return false;
    }

    meshtastic_MeshPacket *packet = allocDataPacket();
    packet->to = to;
    packet->channel = channel;
    packet->want_ack = to != BROADCAST_NODE;

    size_t length = strnlen(text, meshtastic_Constants_DATA_PAYLOAD_LEN);
    memcpy(packet->decoded.payload.bytes, text, length);
#if GATEWATCH_APPEND_BELL
    if (length < meshtastic_Constants_DATA_PAYLOAD_LEN) {
        packet->decoded.payload.bytes[length++] = 7;
    }
#endif
    packet->decoded.payload.size = length;

    LOG_INFO("GateWatch TX to=%x ch=%u msg=%.*s", packet->to, packet->channel,
             packet->decoded.payload.size, packet->decoded.payload.bytes);
    service->sendToMesh(packet);
    return true;
}
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

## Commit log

2026-07-23 Push for Project Start.
    [bom.csv]
2026-08-13 Add files via upload
    adding the schematic and board layout
    [bom.csv, gatewatch.kicad_pcb, gatewatch.kicad_sch]
2026-08-13 Add files via upload
    adding 3d models
    [.step, GateWatch_Base.stl, GateWatch_PrintPlate.stl]
